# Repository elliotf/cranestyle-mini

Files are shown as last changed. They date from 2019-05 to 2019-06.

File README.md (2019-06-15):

# My take on the "Cranestyle mini"

# TODO
* end plates
  * fan mount to cool electronics?
    * until I've mounted a heat spreader under the duet wifi
* make Y belt clamp hold belts closer to extrusion
* wire hotend
  * replace fan wiring with longer wires
* wire heated build plate
* Y carriage
  * print or cut out of aluminum
  * include strain relief for wiring
* heat spreader/build surface
  * cut out of aluminum
* insulate under HBP
* auto BOM-building via parsing comments from openscad
  * look into what nophead did for the mendel90

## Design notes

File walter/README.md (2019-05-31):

# A subset of walter's mini cranestyle design files

Walter is awesome, and is the person that pointed me to this 3d printer design.

I am using some of his parts, as some of these are pretty complex (X carriage) and I don't know if I'll be able to reproduce his work in openscad, and want to get printing with this printer soon.

For more information, see:

http://thrinter.com/cranestyle-mini-guideways-version/
https://cad.onshape.com/documents/fd10786b1b3cdaaf88ec3a8d

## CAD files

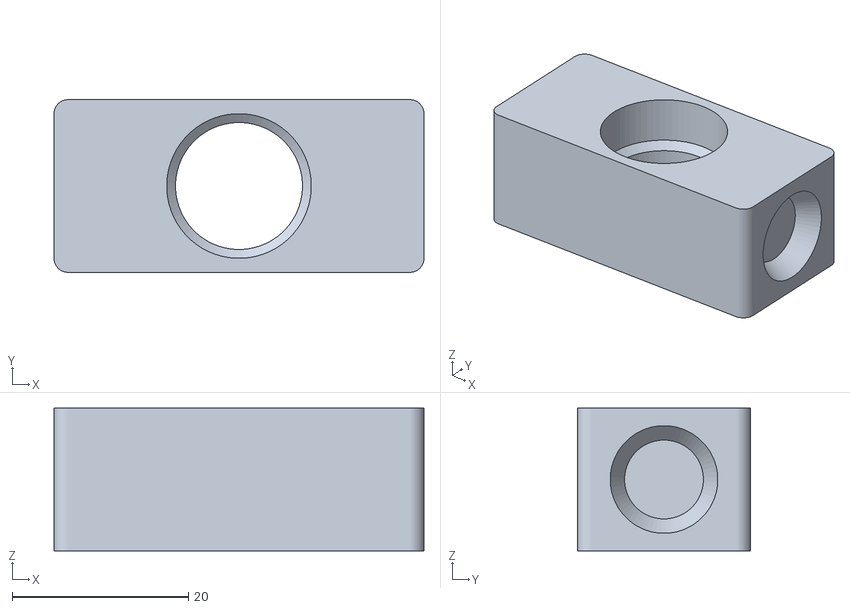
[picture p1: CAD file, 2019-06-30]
renders/extruder-swivel.stl
42.0 x 19.6 x 16.2

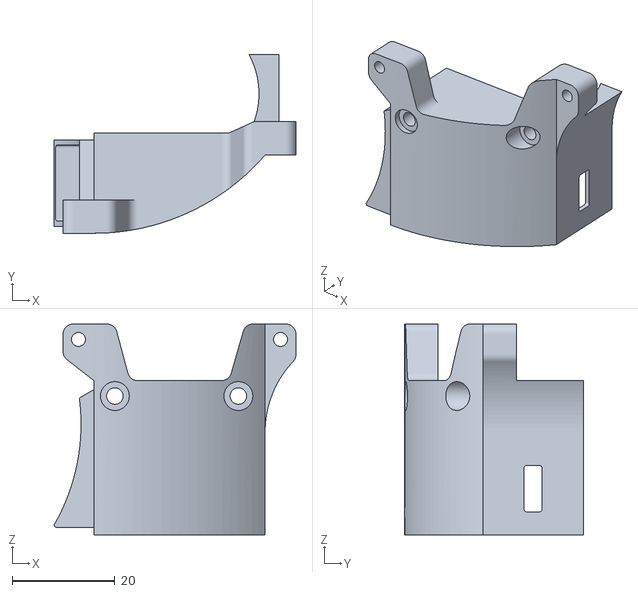
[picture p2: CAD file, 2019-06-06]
walter/Extruder Fan Mount - Extruder Fan Mount.stl
47.0 x 34.7 x 41.0

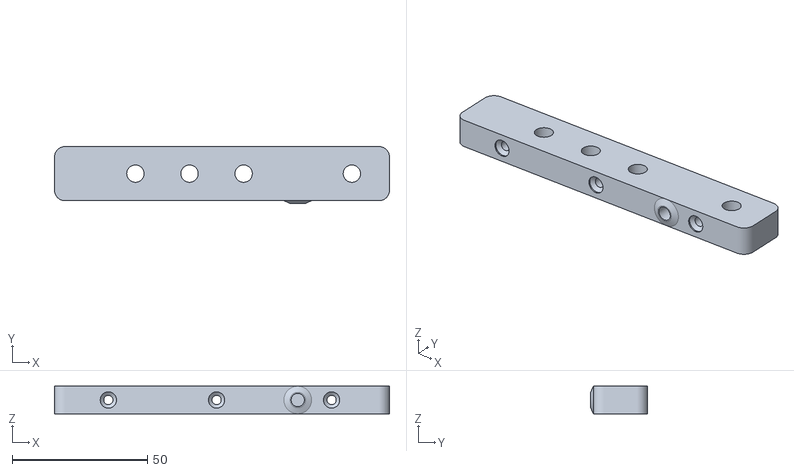
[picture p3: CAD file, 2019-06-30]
renders/end-cap-front.stl
123.8 x 21.0 x 10.2

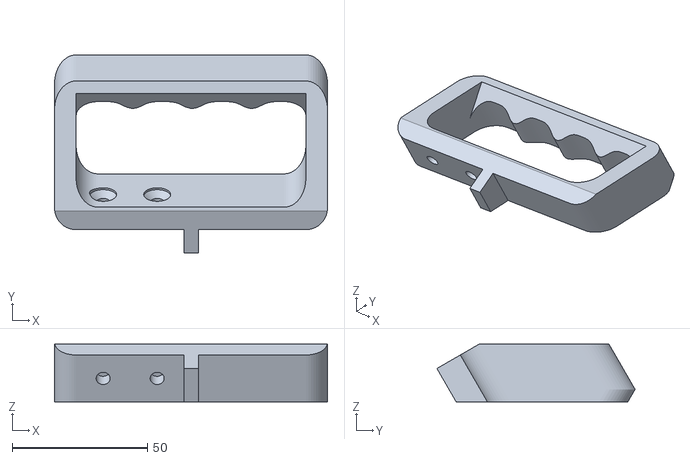
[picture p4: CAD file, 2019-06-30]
renders/handle.stl
101.0 x 73.3 x 21.3

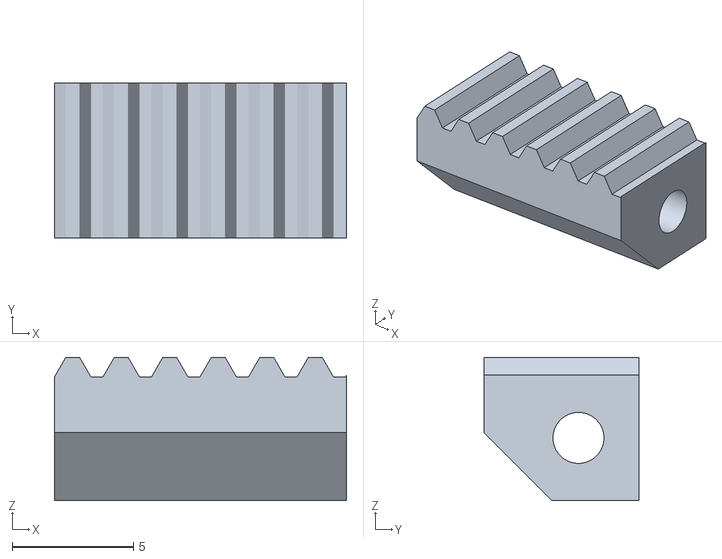
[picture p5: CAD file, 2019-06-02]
walter/X-Carriage - Belt Tensioner.stl
12.0 x 6.40 x 5.90

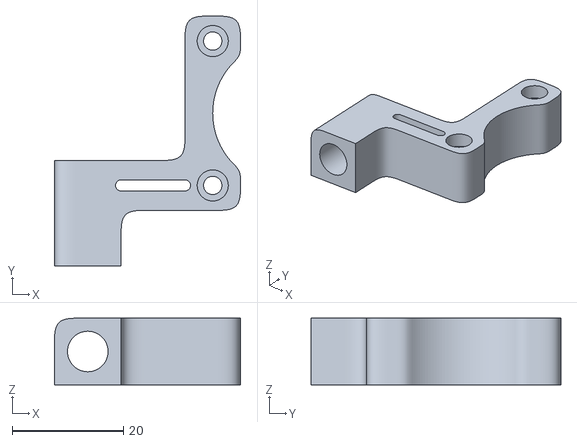
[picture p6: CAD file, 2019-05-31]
walter/Stabilizer Wheel Mount.stl
33.5 x 45.0 x 12.0

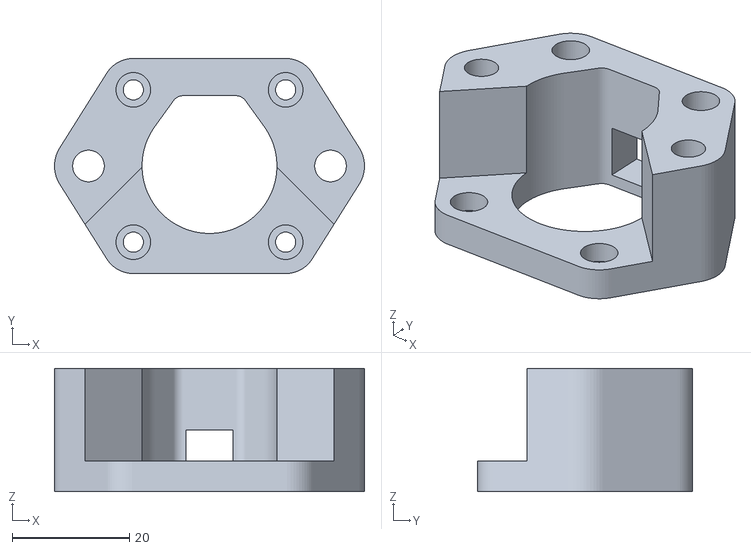
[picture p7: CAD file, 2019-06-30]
renders/y-motor-mount.stl
52.9 x 36.7 x 21.0

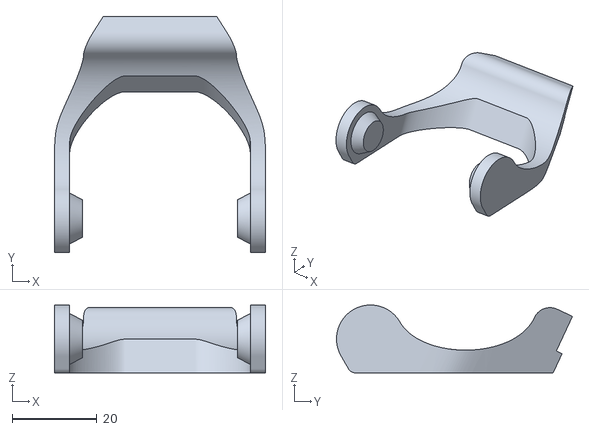
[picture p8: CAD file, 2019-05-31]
walter/Dual Axis Extruder Mount - Bracket.stl
49.7 x 55.6 x 16.0

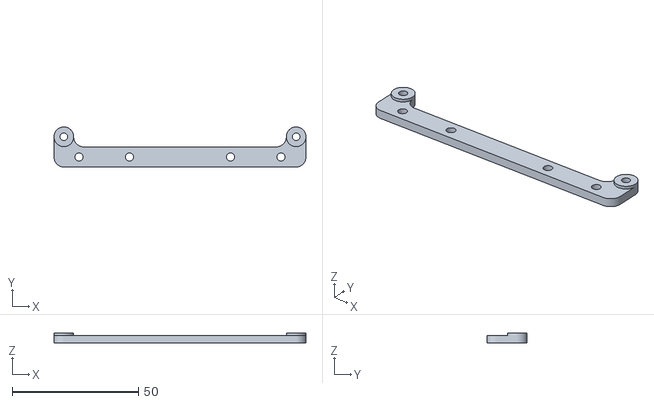
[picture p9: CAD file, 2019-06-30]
renders/duet-mount.stl
99.8 x 15.9 x 4.00

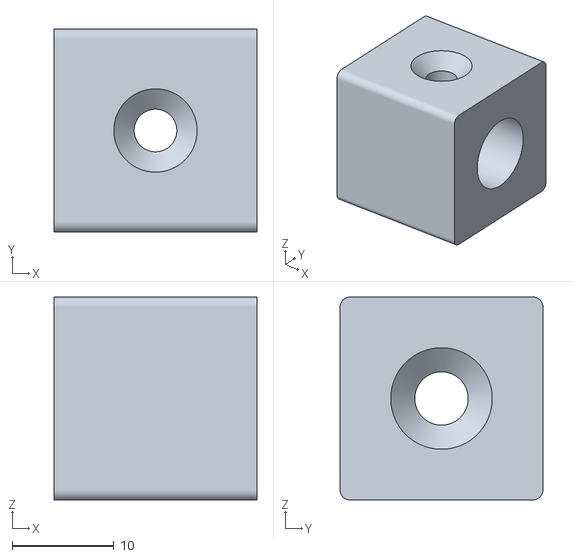
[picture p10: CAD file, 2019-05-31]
walter/Filament Tube Guide.stl
20.0 x 20.0 x 20.0

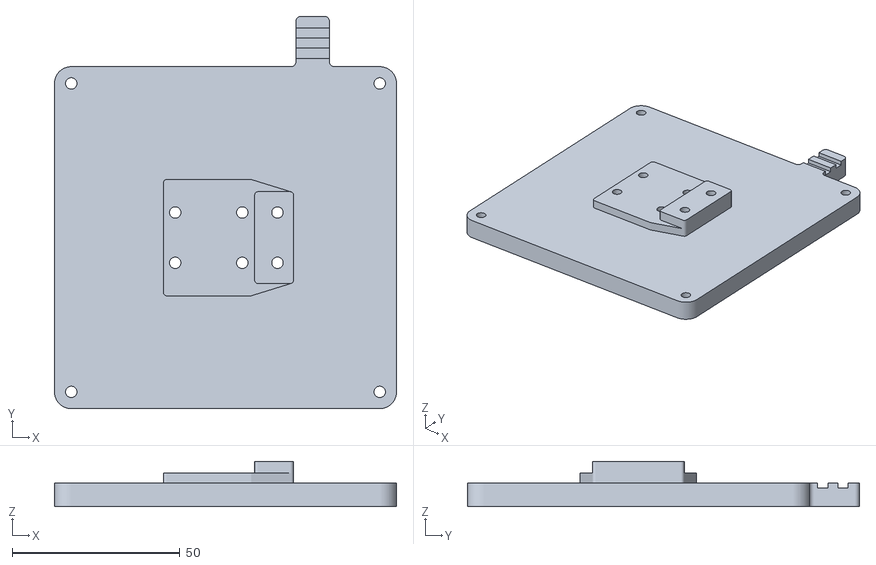
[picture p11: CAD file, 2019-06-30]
renders/y-carriage-printed.stl
102.0 x 117.0 x 13.5

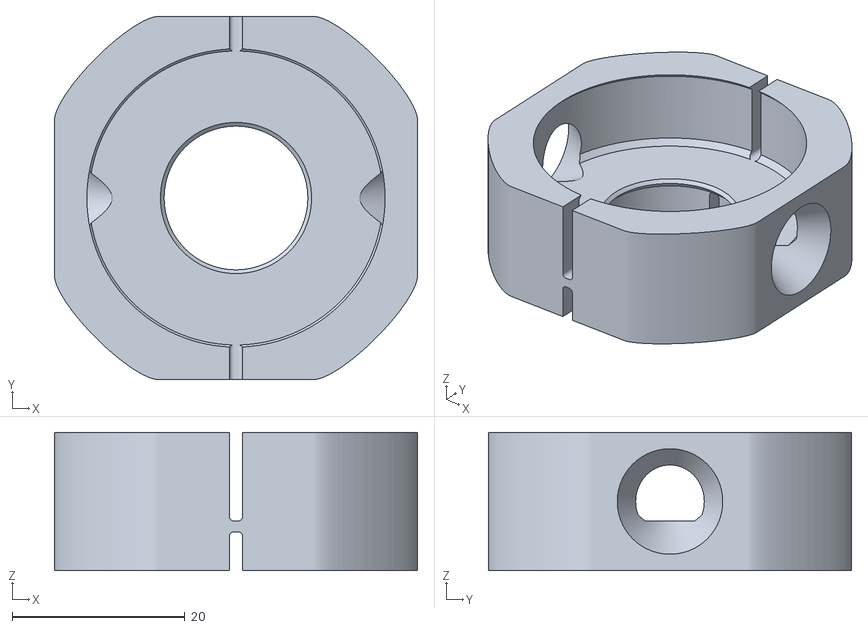
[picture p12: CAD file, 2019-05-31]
walter/Dual Axis Extruder Mount - Swivel.stl
42.0 x 42.0 x 16.0

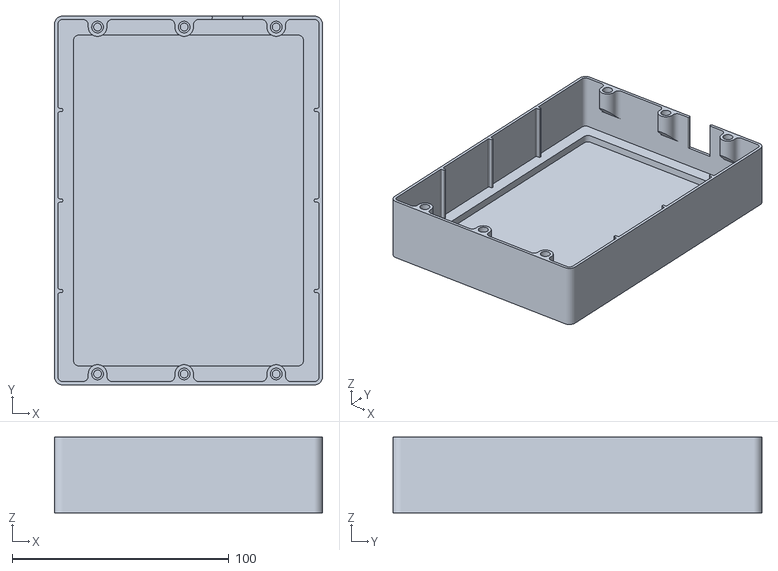
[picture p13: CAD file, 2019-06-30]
renders/bottom_cover.stl
123.8 x 170.4 x 35.0

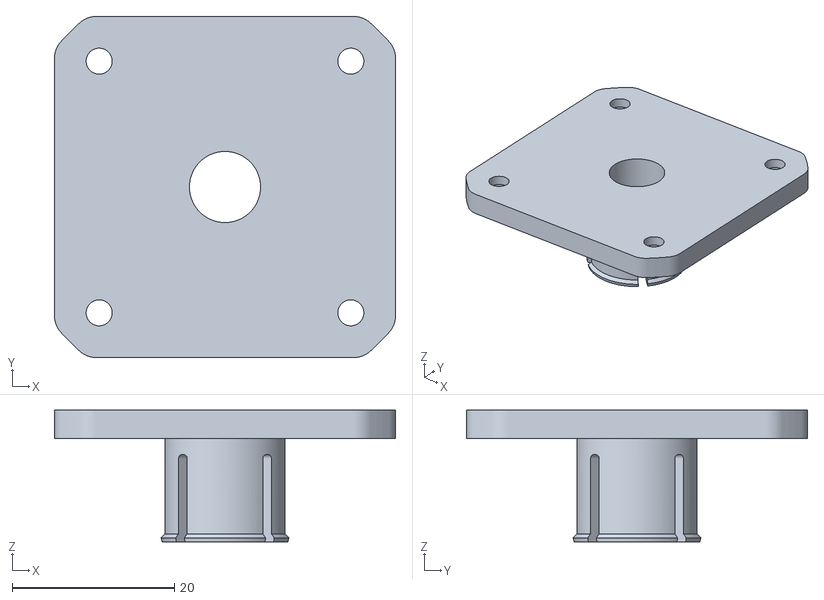
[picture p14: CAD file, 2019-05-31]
walter/Dual Axis Extruder Mount - Motor Plate.stl
42.0 x 42.0 x 16.2

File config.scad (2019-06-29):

include <./lib/util.scad>;
include <./lib/vitamins.scad>;

tolerance = 0.2;
extrude_width = 0.4;
wall_thickness = extrude_width*3;

countersink_all_the_things = 1;

room_below_extrusion_for_electronics = 34;

extrusion_mount_screw_diam = m5_diam;
extrusion_mount_screw_head_diam = (countersink_all_the_things) ? m5_fsc_head_diam : m5_nut_diam;

m2_diam = 2;
m2_thread_into_hole_diam = 1.8;
m2_loose_diam = m2_diam + tolerance*1.5;

m3_thread_into_hole_diam = 2.9;
m3_loose_diam = m3_diam + tolerance;

m5_thread_into_hole_diam = 4.9;
m5_loose_diam = 5+tolerance;

extrusion_width = 20;

leadscrew_diam = 5;
leadscrew_hole_diam = 6.5;
leadscrew_nut_shaft_diam = 8.5;
leadscrew_nut_shaft_length = 6.5;
leadscrew_nut_hole_dist = 6.611;
leadscrew_nut_flange_diam = 20;
leadscrew_nut_flange_thickness = 3.25;
leadscrew_nut_mounting_hole_dist = 6.35;
leadscrew_nut_mounting_hole_diam = 2.8; // from walter's -- threading m3 into plastic?
leadscrew_motor_length = 33.5;
x_motor_length = 44;
y_motor_length = 44;

rounded_diam = m3_nut_diam + tolerance*2 + wall_thickness*4;

t_slot_nut_screw_hole_depth = 5;
t_slot_nut_length = 11;

y_idler_in_endcap = true;

// FIXME: adjust these to fit an aluminum heatspreader between the aluminum extrusion and the duet wifi board to provide a passive heatsink for the drivers -- An idea I got from Walter.
duet_mount_thickness = 3;
duet_mount_bevel_height = 1;

end_cap_rounded_diam = 3+wall_thickness*4;
end_cap_pos_x = 40;
end_cap_extrusion_width_to_cover = 100;
end_cap_thickness = max(5,m3_threaded_insert_diam) + 2*(1.2*2);
end_cap_offset_x = -8;
end_cap_overhang = end_cap_rounded_diam/2;
end_cap_width = end_cap_extrusion_width_to_cover + abs(end_cap_offset_x)*2 + end_cap_overhang*2;
end_cap_height = extrusion_width;

y_extrusion_width = (true) ? 100 : 80;

y_idler_pos_x = -10+y_extrusion_width-30;
y_idler_dist_y_from_extrusion = (y_idler_in_endcap) ? -end_cap_thickness/2 : gt2_toothed_idler_id;
y_idler_dist_z_from_extrusion = 1;

extra_clearance_for_leveling_screws_and_y_idlers = 3;

heated_bed_hole_spacing = 92;
// using what walter is doing, as I don't understand whosawhatsis' version, but he's using something like -24
// I like the idea of a less-cantilevered platform.
y_carriage_pos_x = -10+85;
y_rail_pos_x = -10+y_extrusion_width-10;
y_belt_clamp_hole_dist_from_mgn = 7;

bed_carriage_offset = y_carriage_pos_x-y_rail_pos_x;
build_plate_len = 130;

//leadscrew_pos_y = -leadscrew_nut_flange_diam/2-1;
//leadscrew_pos_y = -11; // we could move it closer with a printed bracket, but it would interfere with the X idler without redefining the X idler Y pos
leadscrew_pos_y = -13; // what walter is using

z_nut_base_height = mgn12c_length/2 - mgn12c_hole_spacing_length/2 + m3_socket_head_diam/2 + extrude_width*2;

gt2_toothed_idler_id_hole = gt2_toothed_idler_id-0.15; // thread the idler pulley shaft into plastic

leadscrew_nut_mounting_hole_depth = z_nut_base_height - leadscrew_nut_flange_thickness - extrude_width*2;

leadscrew_nut_shoulder_below_carriage_holes = 4.5;

x_idler_bevel_height = 1;
idler_shoulder_above_rail = 9/2+5.75;

z_nut_mount_depth = abs(leadscrew_pos_y)+7; // copying from walter
echo("z_nut_mount_depth: ", z_nut_mount_depth);
z_nut_mount_height = idler_shoulder_above_rail - x_idler_bevel_height + mgn12c_hole_spacing_length/2 + mgn12c_length/2;

echo("z_nut_mount_height: ", z_nut_mount_height);
z_nut_body_pos_z = mgn12c_hole_spacing_length/2+idler_shoulder_above_rail-x_idler_bevel_height-z_nut_mount_height/2;

// x_idler_on_z_pos_x = -11; // walter
x_idler_on_z_pos_x = left*(leadscrew_diam/2+gt2_toothed_idler_flange_od/2+1);
x_idler_on_z_pos_y = leadscrew_pos_y-3;
x_idler_on_z_pos_z = z_nut_body_pos_z + z_nut_mount_height/2 + x_idler_bevel_height;

meat_on_far_side_of_idler = gt2_toothed_idler_id_hole/2 + wall_thickness*3;
leadscrew_clearance = 1;
idler_shaft_body_width = meat_on_far_side_of_idler + abs(x_idler_on_z_pos_x) - leadscrew_hole_diam/2 - leadscrew_clearance;
z_nut_mount_width = meat_on_far_side_of_idler + abs(x_idler_on_z_pos_x) + mgn12c_hole_spacing_width/2 + m3_socket_head_diam/2 + extrude_width*2;
z_nut_body_pos_x = x_idler_on_z_pos_x-meat_on_far_side_of_idler+z_nut_mount_width/2;

mgn9_rail_width_allowance = mgn9_rail_width+tolerance;
mgn9_rail_height_allowance = mgn9_rail_height+tolerance;

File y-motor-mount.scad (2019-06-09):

include <./config.scad>;
include <./lib/util.scad>;

module y_motor_mount() {
  /*
  */
  y_motor_side = nema14_side;
  y_motor_screw_diam = nema14_screw_diam;
  y_motor_shoulder_diam = nema14_shoulder_diam;
  y_motor_shoulder_height = nema14_shoulder_height;
  y_motor_hole_spacing = nema14_hole_spacing;
  y_motor_len = nema14_len;

  /*
  y_motor_side = nema17_side;
  y_motor_screw_diam = nema17_screw_diam;
  y_motor_shoulder_diam = nema17_shoulder_diam;
  y_motor_shoulder_height = nema17_shoulder_height;
  y_motor_hole_spacing = nema17_hole_spacing;
  y_motor_len = nema17_len;
  */

  wall_thickness = extrude_width*2;
  motor_screw_hole_diam = y_motor_screw_diam+tolerance*2;
  height = 21;

  belt_opening_angle = 90;
  motor_offset = nema14_side/2-y_motor_side/2;

  extrusion_mount_hole_spacing = y_motor_side + m5_socket_head_diam - 3;
  extrusion_mount_head_hole_diam = extrusion_mount_screw_head_diam + tolerance*3;

  length_to_screw_into_motor = 3;

  open_side_m3_length = 5;
  closed_side_m3_length = 16;
  extrusion_anchor_screw_length = 20;

  meat_above_pulley = open_side_m3_length + m3_socket_head_height - length_to_screw_into_motor;
  echo("meat_above_pulley: ", meat_above_pulley);

  // I'm assuming this little gap is for accessing the motor's set screw while it's mounted, so that the pulley height can be adjusted.
  // Only whosawhatsis knows for sure.
  set_screw_access_width = 8;

  overall_side = y_motor_hole_spacing+rounded_diam;

  translate([0,0,50]) {
    // profile();
  }

  module profile() {
    module body() {
      hull() {
        // main body, defined by motor hole spacing
        translate([0,motor_offset,0]) {
          rounded_square(overall_side,overall_side,rounded_diam,resolution);
        }

        // mount to extrusion
        for(x=[left,right]) {
          translate([x*extrusion_mount_hole_spacing/2,0,0]) {
            rounded_diam = 6;
            accurate_circle(extrusion_mount_screw_head_diam+extrude_width*4,resolution);
          }
        }
      }
    }

    module holes() {
      translate([0,motor_offset,0]) {
        hull() {
          accurate_circle(y_motor_shoulder_diam+1,resolution*2);

          if (set_screw_access_width) {
            translate([0,front*y_motor_shoulder_diam/4,0]) {
              // square off area to access pulley set screw
              // so that it can bridge more cleanly
              rounded_square(set_screw_access_width+5,y_motor_shoulder_diam/2+2,4);
            }
          }
        }

        for(x=[left,right]) {
          for(y=[front,rear]) {
            translate([x*y_motor_hole_spacing/2,y*y_motor_hole_spacing/2]) {
              accurate_circle(motor_screw_hole_diam,16);
            }
          }
        }
      }
    }

    difference() {
      body();
      holes();
    }
  }

  translate([0,-50,0]) {
    // profile();
  }

  module body() {
    linear_extrude(height=height,convexity=3,center=true) {
      profile();
    }
  }

  module holes() {
    translate([0,motor_offset,0]) {
      // maybe for accessing the pulley set screw?
      if (set_screw_access_width) {
        set_screw_access_hole_height = height/2 - y_motor_shoulder_height;
        translate([0,-overall_side/2,height/2-y_motor_shoulder_height-set_screw_access_hole_height/2]) {
          cube([set_screw_access_width,y_motor_side,set_screw_access_hole_height],center=true);

          for(x=[left,right]) {
            translate([x*set_screw_access_width/2,0,0]) {
              rotate([0,0,45-x*45]) {
                // round_corner_filler(3,height);
              }
            }
          }
        }
      }

      // recess motor screw heads by opening, should be able to use 5mm m3
      translate([0,0,-meat_above_pulley+m3_socket_head_height]) {
        for(x=[left,right]) {
          for(y=[rear]) {
            translate([x*y_motor_hole_spacing/2,y*y_motor_hole_spacing/2]) {
              hole(m3_nut_diam+tolerance*2,height,resolution);
            }
          }
        }
      }

      // motor screw heads on the back, should be able to use 15mm m3
      translate([0,0,-closed_side_m3_length+length_to_screw_into_motor]) {
        for(x=[left,right]) {
          for(y=[front]) {
            translate([x*y_motor_hole_spacing/2,y*y_motor_hole_spacing/2]) {
              hole(m3_nut_diam+tolerance*2,height,resolution);
            }
          }
        }
      }

      // belt access
      translate([0,0,-meat_above_pulley]) {
        linear_extrude(height=height,convexity=3,center=true) {
          hull() {
            diam = 16; // both whosawhatsis and walter are using this diam. Not sure why. Maybe it's the pulley diam?
            accurate_circle(diam,resolution);

            for(x=[left,right]) {
              rotate([0,0,x*belt_opening_angle/2]) {
                translate([0,50,0]) {
                  accurate_circle(diam,resolution);
                }
              }
            }
          }
        }
      }
    }

    // extrusion mount screw heads
    for(x=[left,right]) {
      translate([x*extrusion_mount_hole_spacing/2,0,-0.3]) {
        echo("Y MOTOR MOUNT: FCS M5 x ", height+5);
        hole(m5_loose_diam,height*2,resolution);
        translate([0,0,height/2]) {
          m5_countersink_screw(height+2);
        }
      }
    }
  }

  difference() {
    body();
    holes();
  }

  % color("dimgrey") translate([0,motor_offset,height/2]) {
    rotate([180,0,0]) {
      if (y_motor_side == nema14_side) {
        motor_nema14(y_motor_length);
      } else {
        motor_nema17();
      }
    }
  }
}

module to_print() {
  rotate([180,0,0]) {
    y_motor_mount();
  }
}

debug = 0;
if (debug) {
  y_motor_mount();
} else {
  to_print();
}

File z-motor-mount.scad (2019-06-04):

include <./config.scad>;
include <./lib/util.scad>;

adjustment_room_total = 3;
motor_opening_side = nema14_side + adjustment_room_total;
plate_thickness = 4;
motor_screw_hole_diam = nema14_screw_diam+adjustment_room_total; // extra slop to adjust Z motor
motor_screw_mount_width = motor_screw_hole_diam+2*(extrude_width*8);
shoulder_opening_diam = sqrt(2*pow(nema14_hole_spacing,2)) - motor_screw_mount_width;
dist_to_extrusion = abs(leadscrew_pos_y) + mgn12c_surface_above_surface;

z_motor_mount_rear_height = 32; // nema14 motor with leadscrew body is 33.5

side_support_thickness = extrude_width*8;
side_support_length = motor_opening_side + side_support_thickness;

side_support_pos_x = left*(motor_opening_side/2+side_support_thickness/2);
side_support_pos_y = -motor_opening_side/2+side_support_length/2;

extrusion_side_thickness = min(dist_to_extrusion - motor_opening_side/2 - side_support_thickness,extrude_width*8);

extrusion_opening_width = extrusion_width+tolerance;

main_width = max(nema14_hole_spacing+motor_screw_mount_width,motor_opening_side);

between_motor_and_extrusion_width = main_width/2+motor_opening_side/2+side_support_thickness;
extrusion_mount_thickness = (main_width-extrusion_opening_width)/2;
extrusion_mount_overall_depth = dist_to_extrusion+extrusion_width-motor_opening_side/2;

overall_height = z_motor_mount_rear_height + plate_thickness;

bed_side_extrusion_mount_thickness = motor_opening_side/2 - extrusion_width/2;

module z_motor_mount() {
  module plate_profile() {
    module body() {
      coords = [
        [right*nema14_hole_spacing/2,rear*nema14_hole_spacing/2],
        [left*nema14_hole_spacing/2,front*nema14_hole_spacing/2],
      ];

      hull() {
        translate([left*(motor_opening_side/2+side_support_thickness-between_motor_and_extrusion_width/2),motor_opening_side/2+extrusion_side_thickness/2,0]) {
          rounded_square(between_motor_and_extrusion_width,extrusion_side_thickness,side_support_thickness);
        }
        translate([side_support_pos_x,side_support_pos_y,0]) {
          rounded_square(side_support_thickness,side_support_length,side_support_thickness);
        }
        for(coord=coords) {
          translate(coord) {
            accurate_circle(motor_screw_mount_width,resolution);
          }
        }
      }

      for(x=[left,right]) {
        translate([x*(main_width/2-extrusion_mount_thickness/2),motor_opening_side/2+extrusion_mount_overall_depth/2,0]) {
          rounded_square(extrusion_mount_thickness,extrusion_mount_overall_depth,side_support_thickness);
        }

        translate([x*(extrusion_opening_width/2),motor_opening_side/2+extrusion_side_thickness,0]) {
          rotate([0,0,45+x*45]) {
            round_corner_filler_profile(side_support_thickness);
          }
        }
      }

      translate([left*(main_width/2),motor_opening_side/2+extrusion_side_thickness,0]) {
        rotate([0,0,90]) {
          round_corner_filler_profile(side_support_thickness);
        }
      }
    }

    module holes() {
      for(x=[left,right]) {
        for(y=[front,rear]) {
          translate([x*nema14_hole_spacing/2,y*nema14_hole_spacing/2,0]) {
            accurate_circle(motor_screw_hole_diam,resolution);
          }
        }
      } 

      accurate_circle(shoulder_opening_diam,resolution*2);

      rotate([0,0,-45]) {
        translate([motor_screw_mount_width/2,0,0]) {
          square([motor_screw_mount_width,shoulder_opening_diam],center=true);

          // round out the area by the mounting holes
          for(y=[front,rear]) {
            translate([0,y*(shoulder_opening_diam)/2,0]) {
              rotate([0,0,135-y*45]) {
                round_corner_filler_profile(motor_screw_mount_width);
              }
            }
          }
        }
      }
    }

    difference() {
      body();
      holes();
    }
  }

  module body() {
    // motor hole plate
    translate([0,0,plate_thickness-overall_height/2]) {
      linear_extrude(height=overall_height,center=true,convexity=3) {
        plate_profile();
      }
    }
  }

  module holes() {
    // holes to mount to extrusion
    for(x=[left,right]) {
      for(z=[top,bottom]) {
        translate([x*(main_width/2),dist_to_extrusion+extrusion_width/2,plate_thickness-overall_height/2+z*overall_height/4]) {
          rotate([0,90,0]) {
            if (countersink_all_the_things) {
              m5_countersink_screw(16);
              echo("Z MOTOR MOUNT: FCS M5 x ", extrusion_mount_thickness+5);
            } else {
              echo("m5 screw length for mounting Z motor (socket head): ", extrusion_mount_thickness-m5_socket_head_height+5);
              hole(5+tolerance,60,resolution);
              hole(m5_socket_head_diam_diam+tolerance,m5_socket_head_height*2,resolution);
            }
          }
        }
      }
    }

    translate([0,-motor_opening_side/2,-overall_height]) {
      cube([motor_opening_side*2,motor_opening_side*2,overall_height*2],center=true);
    }

    translate([right*(main_width/2),motor_opening_side/2,-overall_height/2]) {
      rotate([0,0,90]) {
        round_corner_filler(side_support_thickness,overall_height);
      }
    }
  }

  module bridges() {
    // side support arm
    translate([side_support_pos_x,0,0]) {
      hull() {
        translate([0,side_support_pos_y,plate_thickness/2]) {
          rounded_cube(side_support_thickness,side_support_length,plate_thickness,side_support_thickness);
        }
        translate([0,motor_opening_side/2,-z_motor_mount_rear_height+1]) {
          rounded_cube(side_support_thickness,side_support_thickness,2,side_support_thickness);
        }
      }
    }
  }

  difference() {
    body();
    holes();
  }
  bridges();
}

module to_print() {
  rotate([0,180,0]) {
    z_motor_mount();
  }
}

module z_motor_assembly() {
  z_motor_mount();

  % color("dimgrey") motor_nema14(leadscrew_motor_length);
}

z_motor_assembly();

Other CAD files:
renders/x-min-cover.stl
walter/Left Extruder Cable Clip.stl
renders/y-endstop-mount.stl
renders/x-max-cover.stl
for_render/extruder-motor-plate.scad
assembly.scad
bmg-spacer.scad
duet-wifi-mount.scad
end-caps.scad
extruder-mount.scad
for_render/bottom_cover.scad
for_render/duet-mount.scad
for_render/end-cap-front.scad
for_render/end-cap-rear.scad
for_render/extruder-bracket.scad
for_render/extruder-swivel.scad
for_render/handle.scad
for_render/hotend-fan-mount.scad
for_render/m2-tnut.scad
for_render/part-cooling-duct.scad
for_render/tnut-cable-clip.scad
for_render/tnut-m2-nut.scad
for_render/tnut-zip-tie-anchor.scad
for_render/tslot-filler.scad
for_render/x-carriage-belt-tensioner.scad
for_render/x-carriage.scad
for_render/x-idler.scad
for_render/x-max-cover.scad
for_render/x-min-cover.scad
for_render/x-motor-threaded-insert-nut-holder.scad
for_render/y-belt-carriage-mount.scad
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

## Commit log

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2019-04-27 Random libraries + Bondtech BMG spacer
    Since I'm going to try walter's method of mounting the extruder and I
    don't want to bother getting shorter screws, we need a spacer.
    [bmg-spacer.scad, config.scad]
2019-04-27 My take on the y carriage
    Because it's fun to reinvent the wheel!
    Probably closer to walter's than whosawhatsis'
    [config.scad, y-motor-mount.scad]
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2019-04-27 Avoid distracting diffs on *.gcode/*.stl
2019-05-10 Progress, but needs work to be walter-compatible
    Specifically, it looks like the X MGN carriage would collide with the Z
    nut holder too early.
    [y-motor-mount.scad, z-nut-mount.scad]
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2019-05-10 Bridges, assuming we'll print it on its face
    [z-nut-mount.scad]
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2019-05-17 WIP, Z motor mount, nema17 Y mount, Z nut
    [assembly.scad, config.scad, x-carriage.scad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]
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2019-05-19 Climbing out of the Y belt clamp hole
    [Pulley_T-MXL-XL-HTD-GT2_N-tooth.scad, config.scad, y-belt-clamp.scad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]
2019-05-19 I think I made it out the other side
    We'll see how the belt clamp fits.
    [assembly.scad, end-caps.scad, handle.scad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]
2019-05-19 Duet wifi mounting bracket
    Not sure what I'm going to do about cooling, but there's probably room
    for thermal pads and an aluminum block under there.
    Could probably drill through a chunk of aluminum and mount it on t-slots
    with some thermal paste, then put some thermal pads on the bottom of it
    to interface with the duet board near the drivers.
    [assembly.scad, config.scad, duet-wifi-mount.scad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]
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2019-05-20 Align Z-side X idler with X carriage belt holder
    [config.scad, z-nut-mount.scad]
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2019-05-20 Updated STLs
    I somehow missed updating the Y belt clamp previously, so let's just
    update them all.
    [duet-mount.scad, duet-mount.stl, end-cap-front.stl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]
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2019-05-21 Y idlers on too-long screws seem to tilt. :(
    So going back to y-idler-in-end-cap plan. :(
    [assembly.scad, config.scad, z-nut-mount.scad]
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2019-05-22 More work on duet mounting
    Specifically, the ports/buttons/LEDs are accessible
    [assembly.scad, config.scad, duet-wifi-mount.scad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]
2019-05-22 Allow Z motor wire connect to be more protected
    Prior to this, the Z motor wire connector had to hang off of the printer
    on the negative X side because of the front motor mount.
    This way, the Z motor wire can be between the Z motor and the Y motor,
    whcich is a bit better protected from little bumps.
    [assembly.scad, x-idler.scad, z-motor-mount-front.scad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]
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2019-05-23 MOAR COUNTERSINKING
    And misc other stuff, like accurate motor lengths and built-in bridges
    [assembly.scad, config.scad, end-caps.scad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]
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2019-05-24 Ready to try printing end caps for the first time
    [config.scad, end-caps.scad]
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2019-05-25 Bolts came in; Let's counter-sink these bad boys!
    [config.scad, end-caps.scad, y-motor-mount.scad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]
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2019-05-27 Design can handle 2080 or 20100 Y extrusion
    [assembly.scad, config.scad, end-caps.scad]
2019-05-27 Avoid cosmetic defect on end plate
    [end-caps.scad]
2019-05-27 First pass at an electronics cover
    Still need another piece to keep it in place, though.
    [config.scad, electronics-cover.scad, end-caps.scad]
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2019-05-28 Let's not put the motor in the .stl
    [y-motor-mount.scad]
2019-05-28 Commit of WiP from earlier
    I think I'm going to give up on this idea. I'm not sure that it's going
    to be sturdy enough. :(
    [end-caps.scad]
2019-05-29 Compensate for reality
    Good news: 20100 is neat and seems to fit well!
    Bad news: I didn't notice the "european profile" that expects M6 thread
    instead of M5
    [end-caps.scad, y-motor-mount.scad, z-motor-mount.scad]
2019-05-29 Working towards a Z fine adjustment screw
    At least until I get the probe working
    [assembly.scad, config.scad, y-motor-mount.scad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]
2019-05-29 STLS with m6 fixes, z endstop adjustment screw
    [duet-mount.stl, electronics-cover.stl, end-cap-front.stl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]
2019-05-29 Getting Z nut mount ready for X/Z endstops
    [assembly.scad, config.scad, end-caps.scad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]
2019-05-29 STLs with Walter's X carriage, X/Z endstop changes
    [duet-mount.stl, end-cap-front.stl, end-cap-rear.stl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]
2019-05-31 Stiffer Z motor mount
    Now that Walter helped me print PETG decently, I don't need to fudge as
    much.
    [z-motor-mount.scad]
2019-05-31 Provide better access to duet ports
    It's still *technically* a bevel, maybe? Sort of like how Mercedes'
    180deg v12 was a V ?
    [duet-wifi-mount.scad, end-caps.scad]
2019-05-31 Translate walter's m2 tnut
    So that I can more easily control the hole offset
    [assembly.scad, m2-tnut.scad, tnuts.scad]
2019-05-31 The proud m2 tnut, in its natural habitat
    [m2-tnut.stl]
2019-05-31 Commit the subset of Walter's parts I'm using
    [Dual Axis Extruder Mount - Bracket.stl, Dual Axis Extruder Mount - Motor Plate.stl, Dual Axis Extruder Mount - Swivel.stl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]
2019-05-31 I accidentally deleted files while cleaning up
    Ugh. Start over again.
    [y-carriage.scad]
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2019-06-02 Can't match Walter's tolerances
    So split the X carriage and belt tensioner up into two separate prints.
    I'll work up to tuning my printer/settings so that I can print with a
    0.1mm overhang tolerance, but for now I'll just print them separately.
    [X-Carriage - Belt Tensioner.stl]
2019-06-02 Extruder mount uses common bearings
    Maybe I'm mistaken or missing something, but I can't even find bearings
    that are 15mm ID, 35mm OD, and 9mm thick.
    Instead, use two 625 bearings and an M5 hex head bolt to use as the
    swivel shaft.
    [extruder-mount.scad]
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2019-06-02 Reduce Z space overhead caused by mech endstop
    It looks like this won't be necessary, since the X motor is going to hit
    the build plate glass before we need to worry about this.
    [assembly.scad, z-nut-mount.scad]
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2019-06-02 Use correct STLs from walter's design
    [Extruder Fan Mount - Extruder Fan Mount.stl, Extruder Fan Mount.stl]
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2019-06-04 Slightly simpler solution
    Assume we're going to need spacers between extrusion mount and motor
    [extruder-mount.scad]
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2019-06-06 Many changes, mostly end caps
    * better access to duet ports
    * more protection for duet wifi antenna
    * strain relief for rear-entering cables
    * simpler, more parametric misumi/openbuilds profiles
    * misc t-slot anchors
    [assembly.scad, config.scad, duet-wifi-mount.scad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]
2019-06-06 Walter's fan mount w/ corrected 24mm screw spacing
    [Extruder Fan Mount - Extruder Fan Mount.stl]
2019-06-07 Screws slip into countersink holes
    m3 in particular was a little tight
    [assembly.scad, z-nut-mount.scad]
2019-06-07 STLs with looser countersink screw shafts
    [end-cap-front.stl, end-cap-rear.stl, tnut-cable-clip.stl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]
2019-06-08 Y endstop mount
    I'd like to try sensorless homing, but for now let's get this thing
    working.
    [assembly.scad, config.scad, y-belt-clamp.scad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]
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2019-06-08 Extruder cabling strain relief
    Now with 20% more zip ties
    [extruder-mount.scad]
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2019-06-10 Reorganize t slot stuffs
    Trying to tamp down the # of files, this is a start
    [assembly.scad, tnut-cable-clip.scad, tnut-zip-tie-anchor.scad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]
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2019-06-15 More work on sound damping material
    Plan on using ~4mm latex tubing
    [end-caps.scad]
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2019-06-15 Integrate 2040 fan into assembly
    Also, make inside of fan easier to see
    [hotend-fan-mount.scad]
2019-06-15 Fan/cooling stuffs
    Push complexity down into hotend fan mount module
    [assembly.scad, end-caps.scad, hotend-fan-mount.scad]
2019-06-15 Functional 4010 fan model, name fans correctly
    [end-caps.scad, hotend-fan-mount.scad]
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
